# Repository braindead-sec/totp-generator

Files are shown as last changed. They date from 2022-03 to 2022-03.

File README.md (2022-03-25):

# DIY TOTP Generator

A do-it-yourself time-based one-time password generator. You know, for MFA.

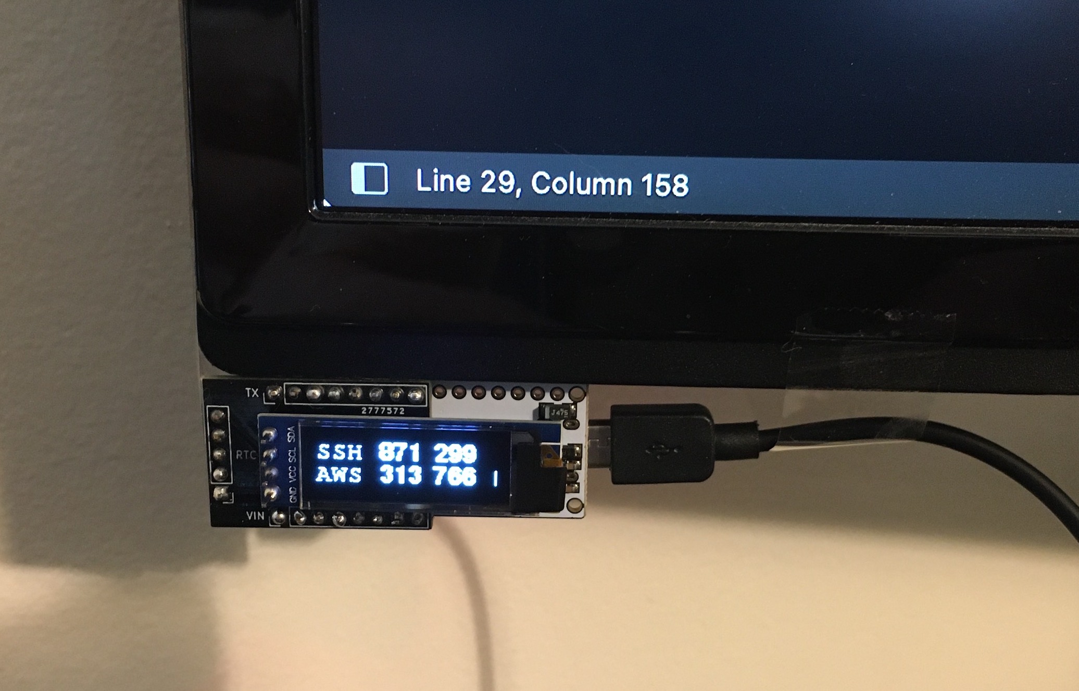
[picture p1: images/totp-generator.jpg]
totp-generator


It's like a cheap open-source [RSA dongle](https://www.tokenguard.com/SecurID-700.asp) that works with any multi-factor authentication service following the [TOTP standard](https://datatracker.ietf.org/doc/html/rfc6238).

Why? Because there are some things I use so frequently (SSH) that it's actually inconvenient to unlock my phone to get the MFA code. With this device mounted on my monitor, I can save *seconds* at a time.

Follow the instructions below to build your own!

### Hardware Components

- Arduino Nano (16MHz ATmega328, 5v) or cheap knock-off
- I2C 128x32 OLED display (SSD1306)
- I2C real-time clock module (DS3231) with battery
- [Custom PCB](custom-pcb/) to integrate components

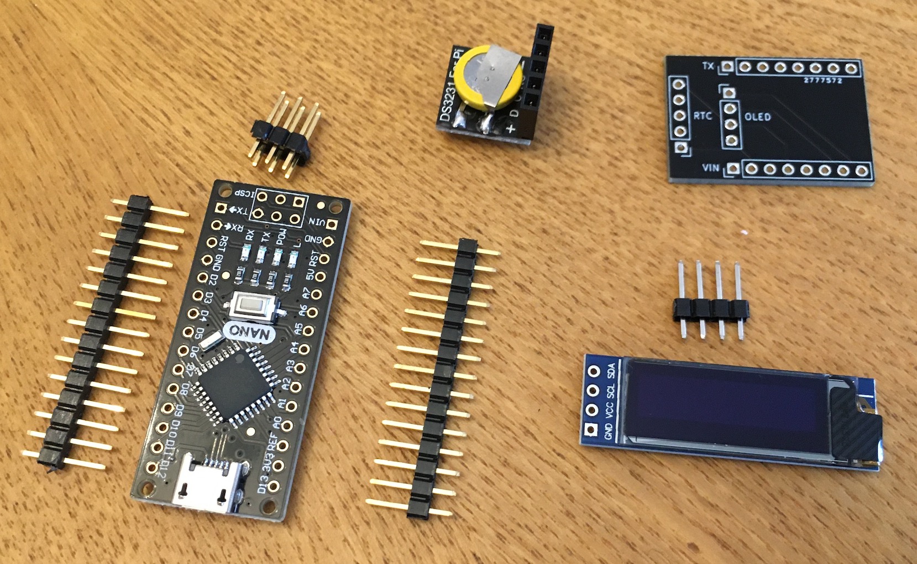
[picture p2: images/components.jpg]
components


### Hardware Assembly

Soldering required. Fine-point solder tip definitely recommended.

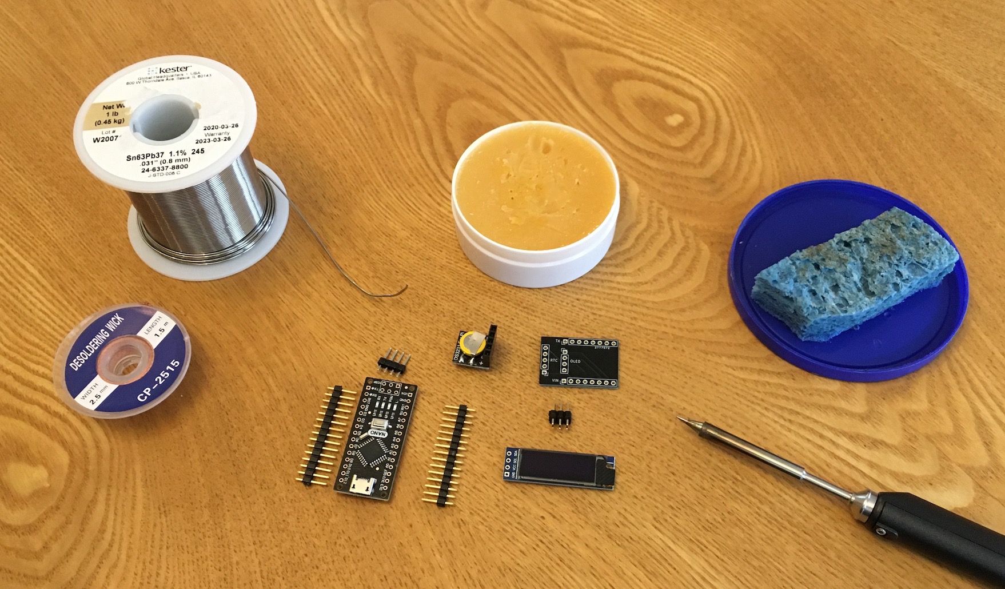
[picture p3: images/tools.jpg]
tools


1. Attach header pins to OLED (short pins and spacers below, long pins above):

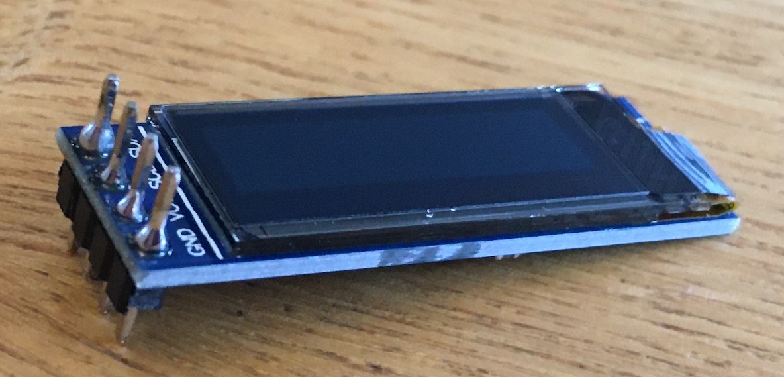
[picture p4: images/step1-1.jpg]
step1-1
   

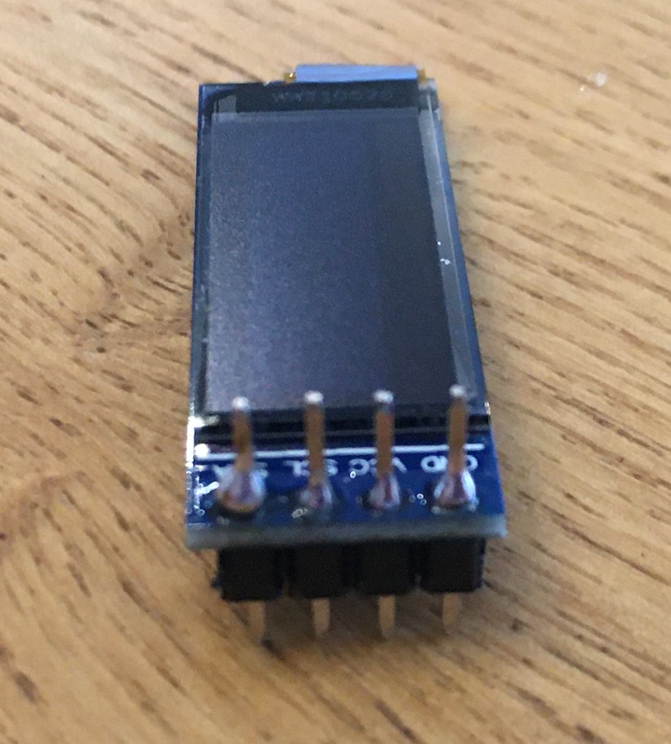
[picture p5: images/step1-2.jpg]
step1-2
   

2. Attach header pins to Nano (note that not all pins are needed). Set the custom PCB in place to make sure the spacing is right - my original design was a hair too wide and set the pins at an angle - but don't solder it in yet. Short pins and spacers should be on the back of the Nano; long pings should protrude through the front:

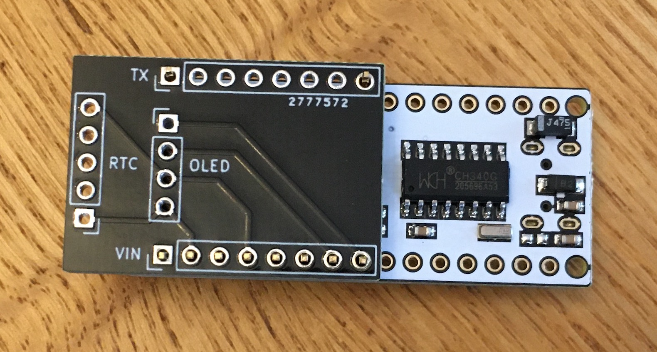
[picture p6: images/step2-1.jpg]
step2-1
   

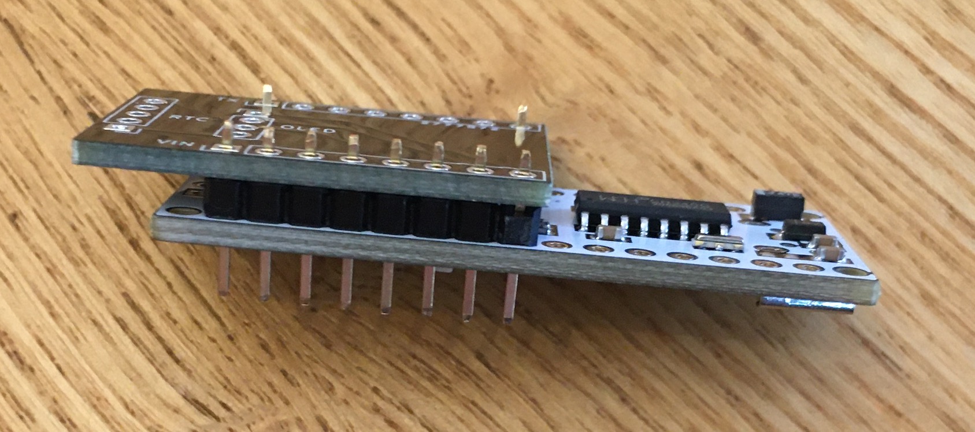
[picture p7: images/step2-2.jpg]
step2-2
   

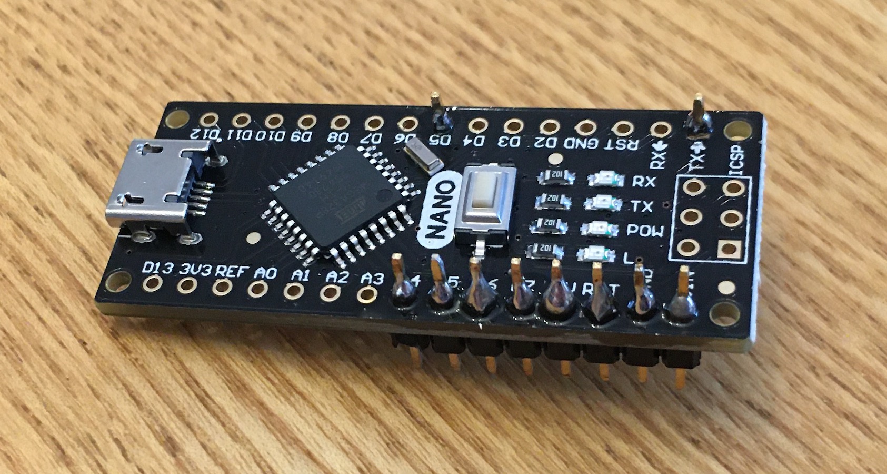
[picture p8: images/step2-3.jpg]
step2-3
   

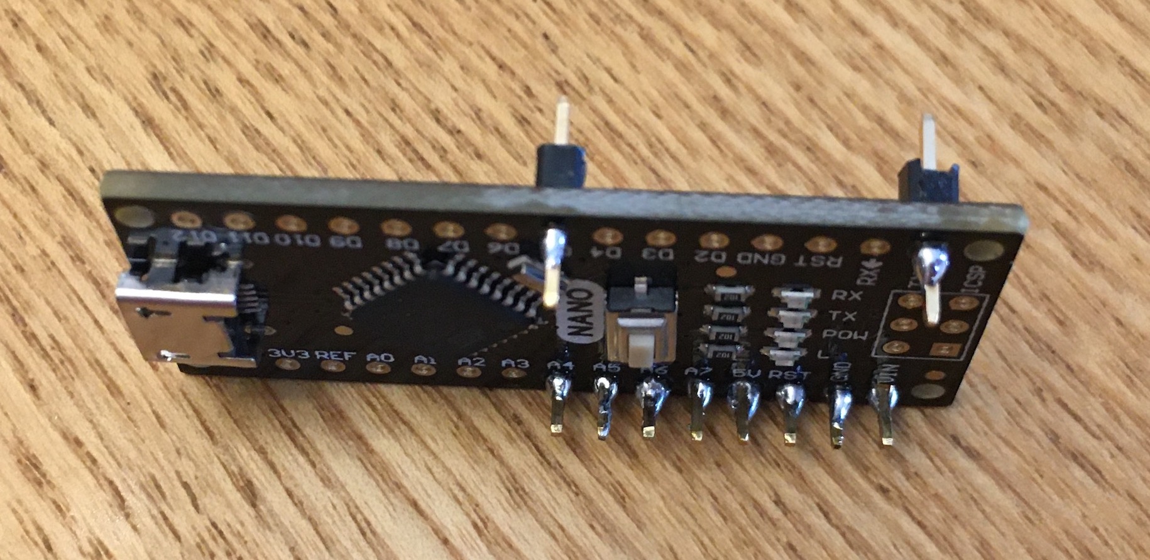
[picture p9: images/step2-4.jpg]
step2-4
   
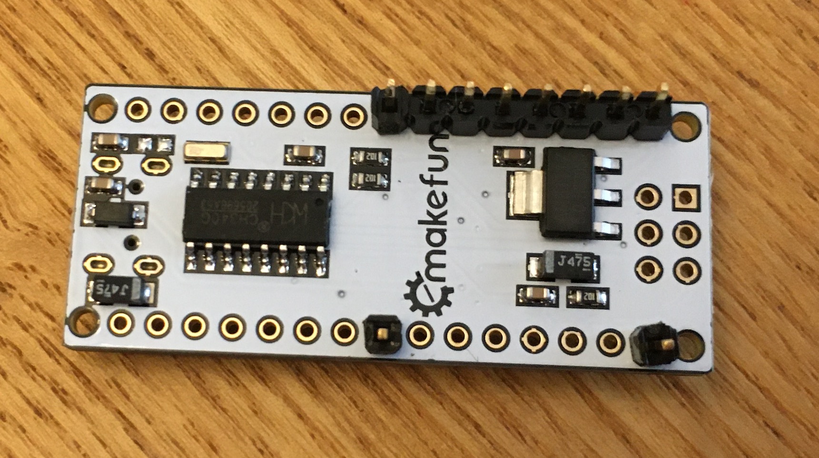
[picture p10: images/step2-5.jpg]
step4-5
   

3. Attach OLED to custom PCB (insert pins through the holes marked OLED, and don't cover the RTC holes!):

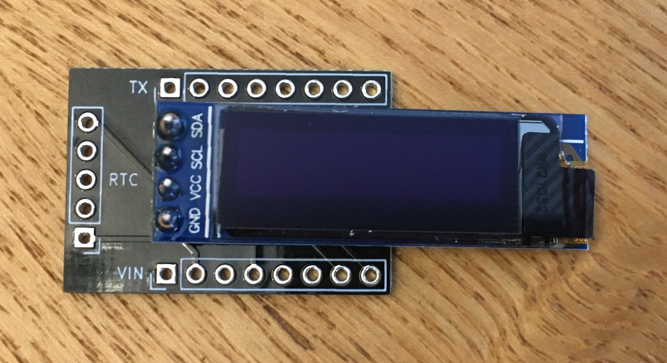
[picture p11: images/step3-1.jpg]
step3-1
   

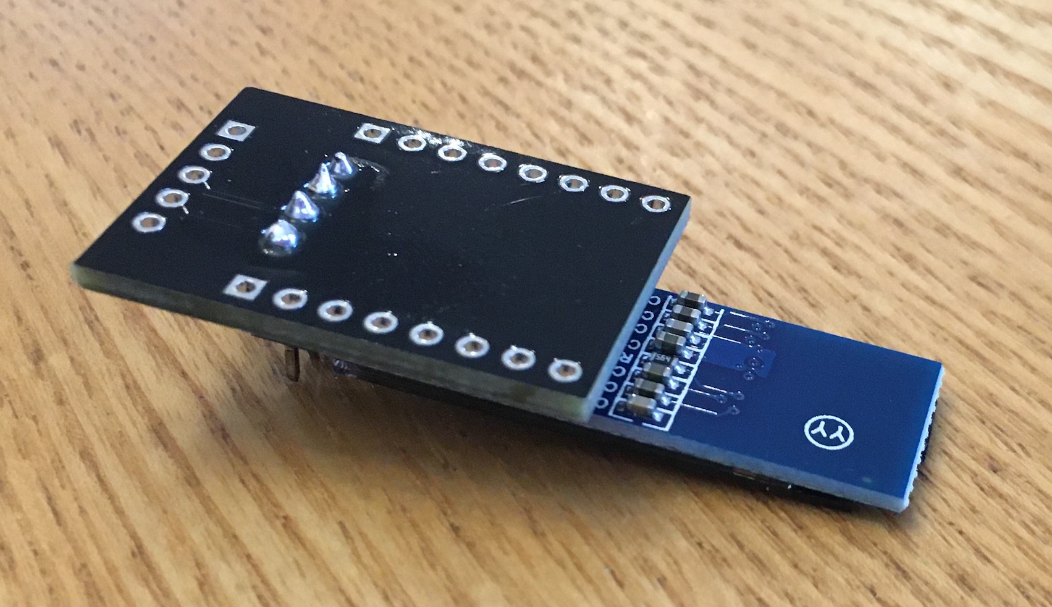
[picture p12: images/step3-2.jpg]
step3-2
   

4. Attach custom PCB to Nano (make sure VIN and TX align on the Nano and custom PCB):

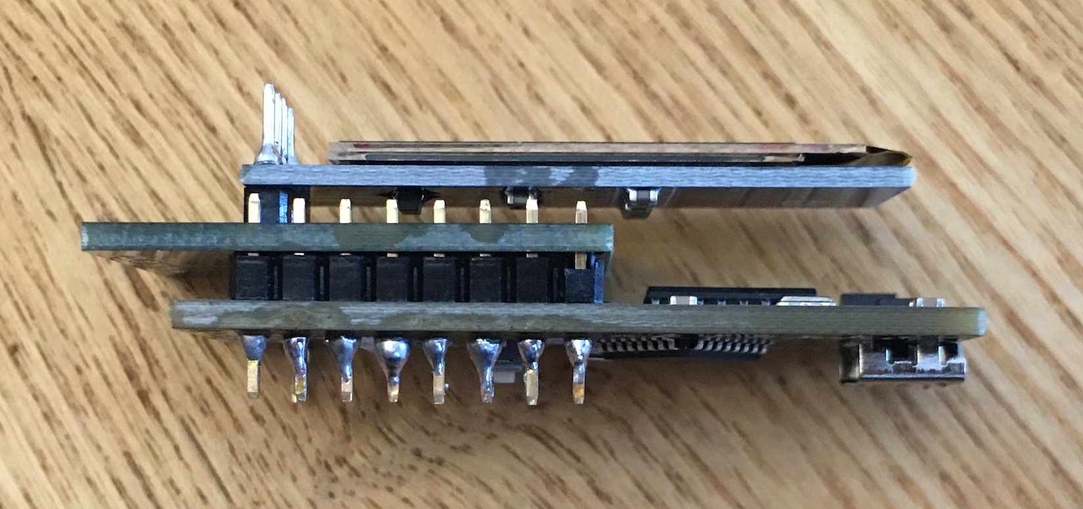
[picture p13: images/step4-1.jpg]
step4-1
   

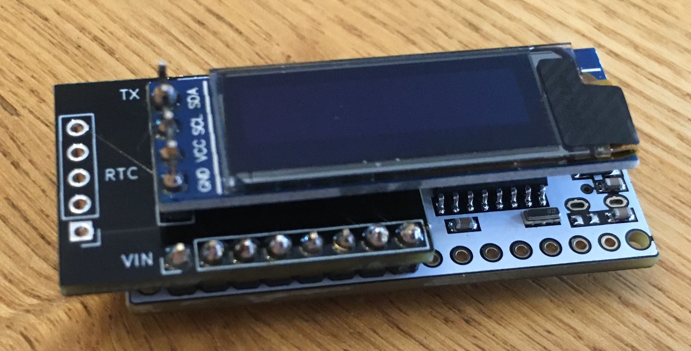
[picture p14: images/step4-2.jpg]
step4-2
   

5. Attach RTC header pins to custom PCB (long pins and spacers below, short pins above):

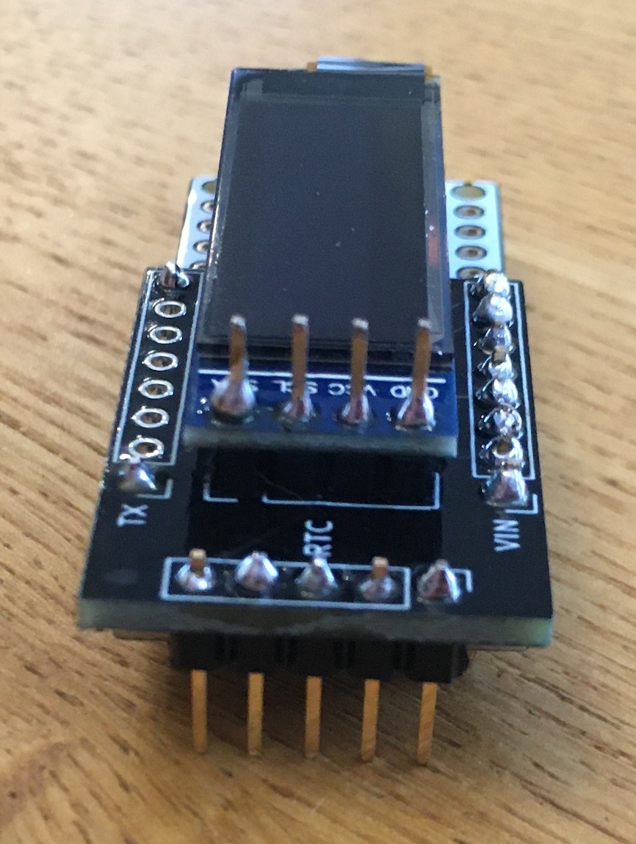
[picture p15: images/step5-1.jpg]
step5-1
   

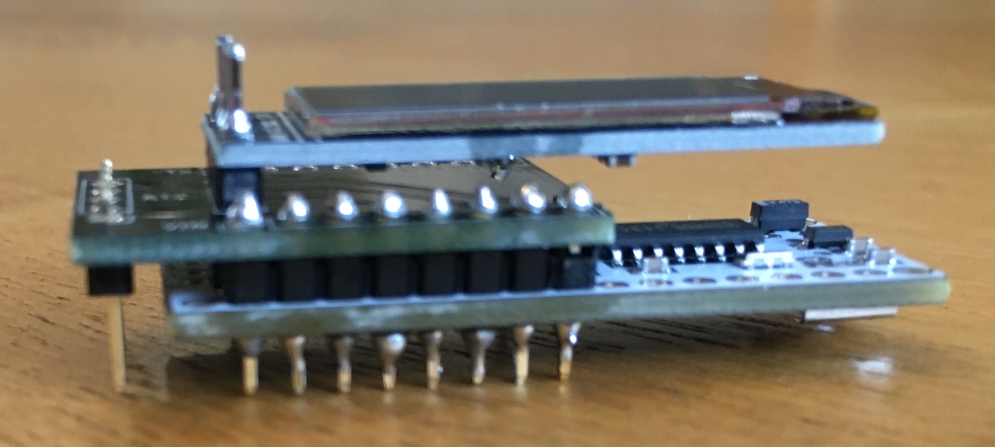
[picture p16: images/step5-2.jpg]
step5-2
   

6. Slide RTC onto its header pins:

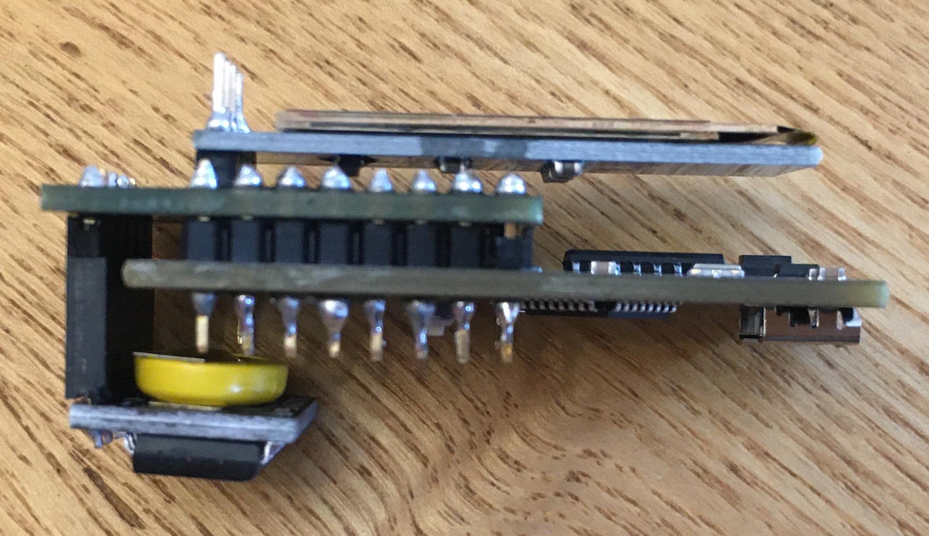
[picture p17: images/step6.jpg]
step6
   

Assembly is now complete!

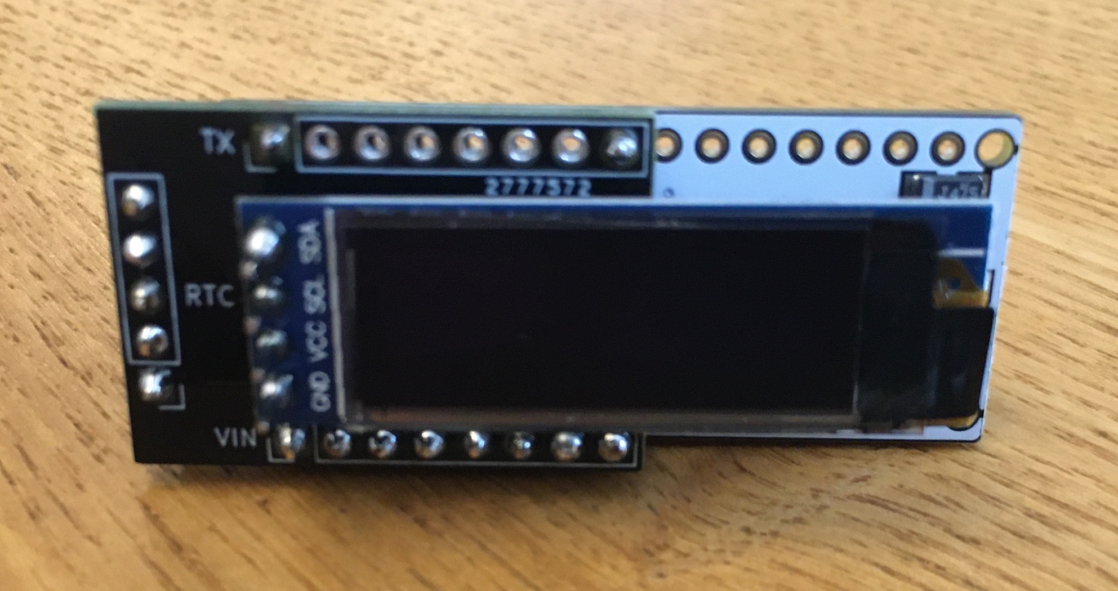
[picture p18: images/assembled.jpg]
assembled


### Software Installation

1. Download [Arduino IDE](https://www.arduino.cc/en/software).

2. [Install required boards](https://support.arduino.cc/hc/en-us/articles/360016119519-How-to-add-boards-in-the-board-manager):

   - `Adafruit AVR Boards` by Adafruit

3. [Install required libraries](https://docs.arduino.cc/software/ide-v1/tutorials/installing-libraries):
   - `Adafruit SSD1306` by Adafruit
   - `Adafruit GFX Library` by Adafruit
   - `RTC` by Manjunath CV
   - `TOTP library` by Luca Dentella

4. Clone or export this GitHub repo.

5. Open the Arduino project (`totp-generator.ino`) in Arduino IDE.

6. Connect your fully assembled device to your computer using a USB data cable. The power light should come on, and it may blink if there is a default program installed to make it do that.

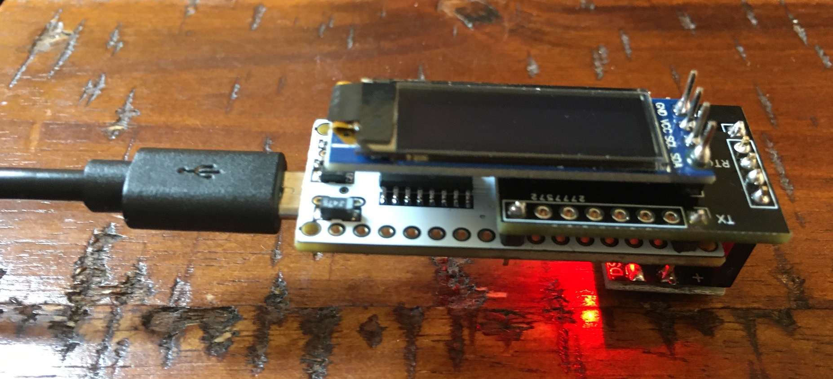
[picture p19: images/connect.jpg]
connect
   

7. From the `Tools` menu in the Arduino IDE, configure these options:
   - Board: Arduino Nano
   - Processor: ATmega 328P
   - Port: whichever one corresponds to the device you just plugged in

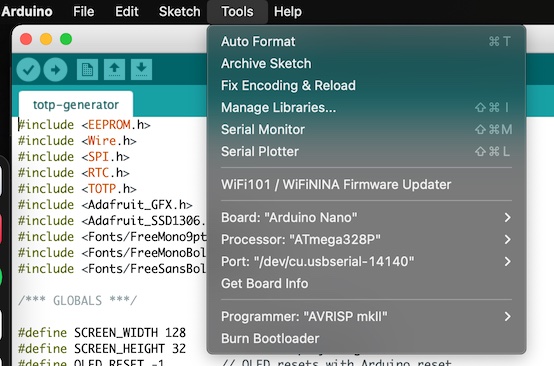
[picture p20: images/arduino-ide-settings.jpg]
arduino-ide-settings
   

8. Click the right-arrow button at the top of the program window to compile the code and upload it to the device.

If everything worked properly up to this point, your device should now be showing either "Connect to set clock" or "Connect to set keys" (depending on the initial RTC setting):

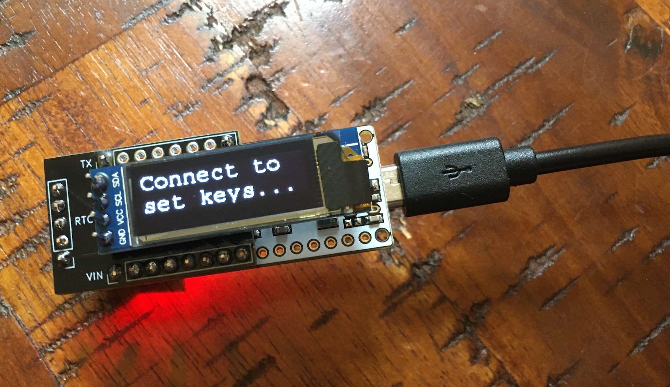
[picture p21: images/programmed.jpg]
programmed


### Software Configuration

1. Install [Python 3](https://www.python.org/downloads/).

2. Install required Python libraries (just `pyserial`):
   
* `pip3 install -r requirements.txt`
   
3. Connect your fully assembled and programmed device to your computer using a USB data cable.

4. Run the Python script:
   
* `python3 setup-device.py`
   
5. Select the USB port corresponding to your device, when prompted.

6. After establishing a serial connection to your device, the script will automatically sync the time from your computer to the RTC.

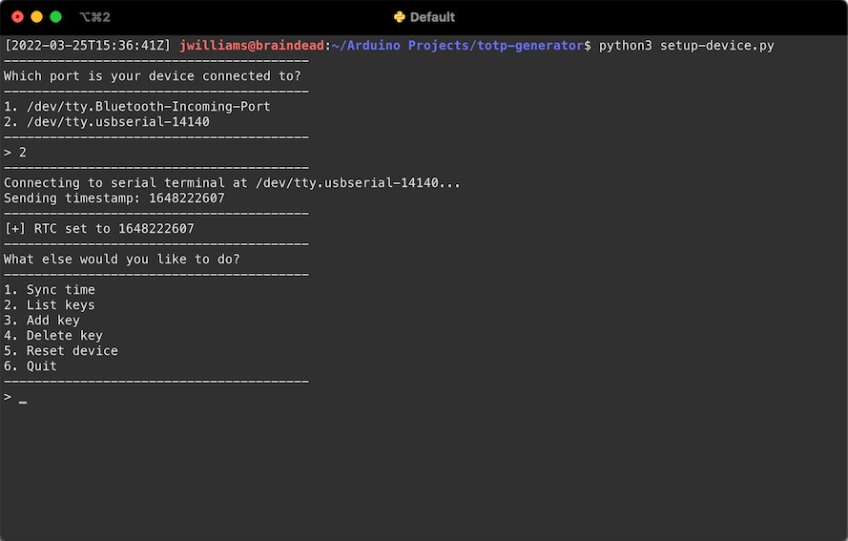
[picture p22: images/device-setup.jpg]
device-setup
   

7. For first-time setup, choose option 5 to initialize the device memory.

8. Choose option 3 to add a key to your device. First enter a three-character label for the key, then enter the key in the standard Base32 format. The device currently supports one or two keys at a time, and will adjust the display accordingly. Keys are recorded in the Arduino's built-in EEPROM without encryption (fair warning).
   - [Google Authenticator](https://support.google.com/accounts/answer/1066447): the app should print your key after completing setup, otherwise you can retrieve the code from the first line of your `.google_authenticator` file
   - [AWS MFA](https://docs.aws.amazon.com/IAM/latest/UserGuide/id_credentials_mfa_enable_virtual.html): use the "Show Secret Key" option during setup

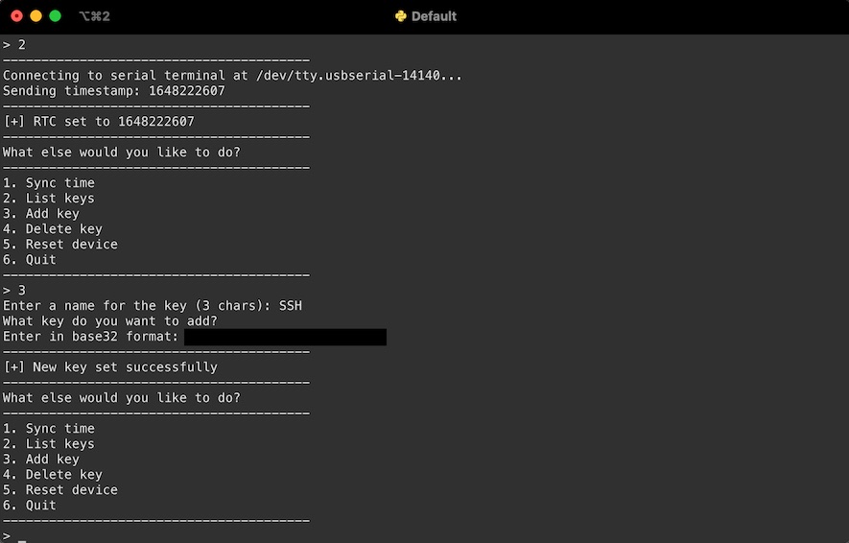
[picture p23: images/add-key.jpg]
add-key
   

9. Use the other menu options to view the labels assigned to keys stored on the device, delete keys, reset the device memory (wipe all keys), and sync the time again. Choose option 6 when you're done.

Setup is now complete! Here's how it should look:

- One key

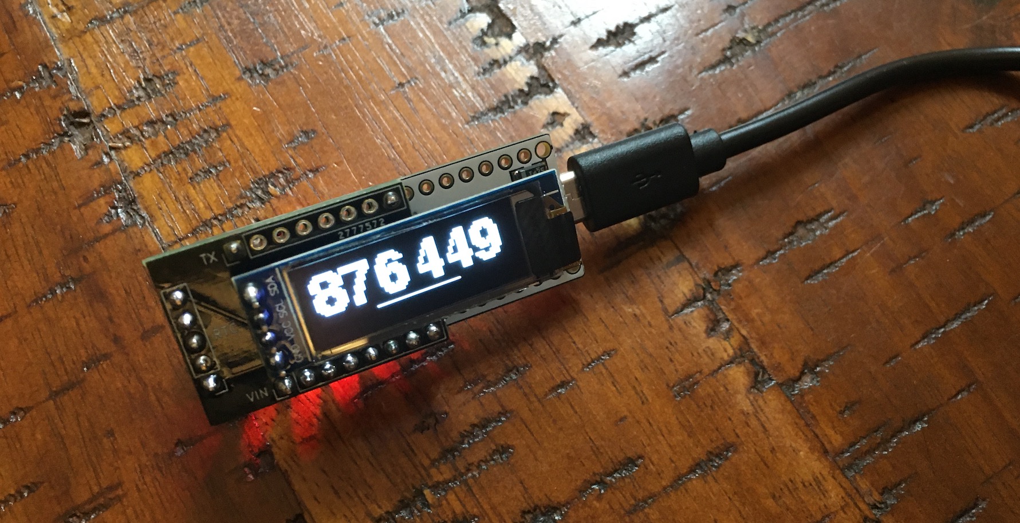
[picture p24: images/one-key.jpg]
one-key
  

- Two keys

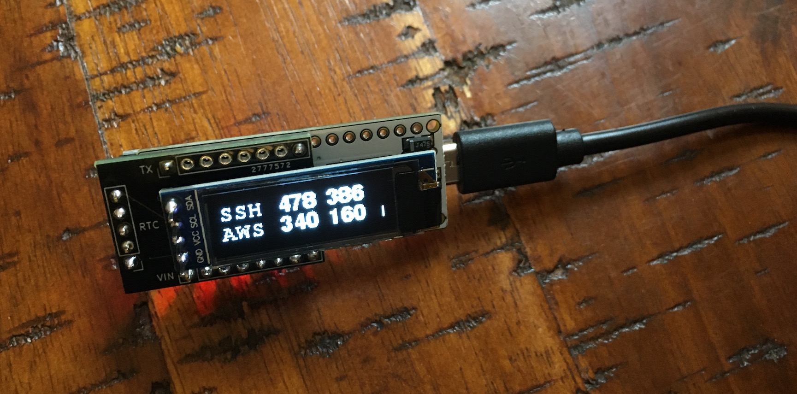
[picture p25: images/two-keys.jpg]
two-keys
  

The display includes a countdown bar to let you know when the code is about to change. It uses a 30-second counter, which is the only time value I've seen used in practice. You can change this value, if necessary, by editing the Arduino code and reprogramming the device.

### Just for Fun ###

if you only intend to use one code, you can modify the Arduino program to use a nicer-looking large font (it's not included by default because of memory constraints).

- Delete this line: `#include <Fonts/FreeMonoBold9pt7b.h>`
- Search for `FreeSansBold9pt7b` and replace all matches with `FreeSansBold18pt7b`
- Delete `display.setTextSize(2);` from the `printCode` function
- Delete all of the code inside the `printTwoCodes` function, so that it just looks like one line: `void printTwoCodes(uint8_t key1, uint8_t key2) {}`
- Compile and upload the new program to your device!

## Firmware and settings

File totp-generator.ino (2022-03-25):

#include <EEPROM.h>
#include <Wire.h>
#include <SPI.h>
#include <RTC.h>
#include <TOTP.h>
#include <Adafruit_GFX.h>
#include <Adafruit_SSD1306.h>
#include <Fonts/FreeMono9pt7b.h>
#include <Fonts/FreeMonoBold9pt7b.h>
#include <Fonts/FreeSansBold9pt7b.h>

/*** GLOBALS ***/

#define SCREEN_WIDTH 128     // OLED display width
#define SCREEN_HEIGHT 32     // OLED display height
#define OLED_RESET -1        // OLED resets with Arduino reset
#define SCREEN_ADDRESS 0x3C  // OLED 2wire bus address

const uint8_t maxKeys = 2;     // Max number of keys to hold
const uint16_t maxKeyLen = 64; // Max key length, in bytes

Adafruit_SSD1306 display(SCREEN_WIDTH, SCREEN_HEIGHT, &Wire, OLED_RESET);
static DS3231 rtc;
uint8_t keysSet = 0;
boolean timeSet = false;

struct DataObj {
  uint16_t keyLen[maxKeys];
  uint8_t keyName[maxKeys][3];
  uint8_t key[maxKeys][maxKeyLen];
};
DataObj settings;

/*** FUNCTIONS ***/

String getTime() {
  String hr = String(rtc.getHours());
  String mn = String(rtc.getMinutes());
  String sc = String(rtc.getSeconds());
  if (hr.length() == 1) hr = "0"+hr;
  if (mn.length() == 1) mn = "0"+mn;
  if (sc.length() == 1) sc = "0"+sc;
  String now = "UTC"+hr+":"+mn+":"+sc;
  return now;
}

void setTime(uint32_t timestamp) {
  rtc.stopClock();
  rtc.setEpoch(timestamp);
  rtc.startClock();
  timeSet = true;
  Serial.print("RTC set to ");
  Serial.println(timestamp);
  printSmallOLED("Time synced!");
  delay(2000);
}

uint8_t getExpiration() {
  uint8_t secs = rtc.getSeconds();
  if (secs >= 30)
    secs = secs - 30;
  return (30 - secs);
}

void printCode(uint8_t keyId) {
  display.clearDisplay();
  display.setFont(&FreeSansBold9pt7b);
  display.setTextSize(2);
  
  TOTP totp = TOTP(settings.key[keyId], settings.keyLen[keyId]);
  char* code = totp.getCode(rtc.getEpoch());
  
  // Print first 3 digits
  display.setCursor(0,24);
  for (uint8_t i=0; i<3; i++)
    display.print(code[i]);
  
  // Print last 3 digits
  display.setCursor(64,24);
  for (uint8_t i=3; i<6; i++)
    display.print(code[i]);
  
  // Print countdown bar
  uint8_t expiry = getExpiration();
  uint8_t progress_length = (SCREEN_WIDTH / 30) * expiry;
  uint8_t progress_start = (SCREEN_WIDTH / 2) - (progress_length / 2);
  display.drawFastHLine(progress_start, SCREEN_HEIGHT - 1, progress_length, SSD1306_WHITE);
  display.display(); 
}

void printTwoCodes(uint8_t key1, uint8_t key2) {
  uint8_t i;
  display.clearDisplay();

  TOTP totp1 = TOTP(settings.key[key1], settings.keyLen[key1]);
  TOTP totp2 = TOTP(settings.key[key2], settings.keyLen[key2]);

  uint32_t timeNow = rtc.getEpoch();
  char* code1 = totp1.getCode(timeNow);
  char* code2 = totp2.getCode(timeNow);
  
  // Print code 1
  display.setTextSize(1);
  display.setFont(&FreeMono9pt7b);
  display.setCursor(0,14);
  for (i=0; i<3; i++)
    display.print((char)settings.keyName[key1][i]);
  display.setFont(&FreeSansBold9pt7b);
  display.setCursor(45,14);
  for (i=0; i<3; i++)
    display.print(code1[i]);
  display.setCursor(83,14);
  for (i=3; i<6; i++)
    display.print(code1[i]);

  // Print code 2
  display.setFont(&FreeMono9pt7b);
  display.setCursor(0,31);
  for (i=0; i<3; i++)
    display.print((char)settings.keyName[key2][i]);
  display.setFont(&FreeSansBold9pt7b);
  display.setCursor(45,31);
  for (i=0; i<3; i++)
    display.print(code2[i]);
  display.setCursor(83,31);
  for (i=3; i<6; i++)
    display.print(code2[i]);

  // Print countdown bar
  uint8_t expiry = getExpiration();
  uint8_t progress_length = (SCREEN_HEIGHT / 30) * expiry;
  display.drawFastVLine(SCREEN_WIDTH - 1, SCREEN_HEIGHT - progress_length, progress_length, SSD1306_WHITE);
  display.display();
}

void printSmallOLED(String text) {
  display.clearDisplay();
  display.setFont(&FreeMono9pt7b);
  display.setTextSize(1);
  display.setCursor(0,11);
  display.print(text);
  display.display();
}

uint8_t getKeyCount() {
  uint8_t numKeys = 0;
  for (uint8_t i=0; i<maxKeys; i++)
    if (settings.keyLen[i] > 0 && settings.keyLen[i] <= maxKeyLen)
      numKeys++;
  return numKeys;
}

void getCommand() {
  String code = Serial.readStringUntil('\n');
  
  if (code == "sync") {
    // Sync the time
    uint32_t newTime = Serial.readStringUntil('\n').toInt();
    setTime(newTime);
  
  } else if (code == "get") {
    // List key names (but not keys)
    // Print the number of keys available
    uint16_t numKeys = getKeyCount();
    Serial.println(numKeys, DEC);
    // Print the ID and name of each
    if (numKeys > 0) {
      for (uint16_t i=0; i<numKeys; i++) {
        Serial.print(i+1);
        Serial.print(": ");
        for (uint8_t j : settings.keyName[i])
          Serial.print(char(j));
        Serial.println();
      }
    }
  
  } else if (code == "set") {
    // Add a new HMAC key
    // Read key name from serial (3 chars)
    String newKeyName = Serial.readStringUntil('\n');
    // Read key from serial
    uint8_t newKey[maxKeyLen];
    uint16_t newKeyLen = Serial.readBytesUntil('\n', newKey, maxKeyLen+1);
    // Make sure there is a key slot available
    uint16_t numKeys = getKeyCount();
    if (numKeys >= maxKeys) {
      Serial.print("Only ");
      Serial.print(maxKeys, DEC);
      Serial.println(" keys allowed");
      return;
    }
    if (newKeyLen >= 10 && newKeyLen <= maxKeyLen) {
      // Update settings
      uint16_t i;
      for (i=0; i<3; i++)
        settings.keyName[numKeys][i] = newKeyName[i];
      settings.keyLen[numKeys] = newKeyLen;
      for (i=0; i<newKeyLen; i++)
        settings.key[numKeys][i] = newKey[i];
      while (i < maxKeyLen) {
        settings.key[numKeys][i] = 0xFF;
        i++;
      }
      EEPROM.put(0, settings);
      // Show result
      keysSet++;
      Serial.println("New key set successfully");
      printSmallOLED("New key set");
      delay(1500);
    } else {
      Serial.println("Invalid key length");
    }

  } else if (code == "del") {
    // Delete an HMAC key
    uint16_t numKeys = getKeyCount();
    // Get the key ID to delete
    uint16_t keyId = Serial.readStringUntil('\n').toInt();
    if (keyId >= numKeys) {
      Serial.println("Invalid key ID");
      return;
    }
    // Cascade remaining keys
    while ((keyId+1) < numKeys) {
      uint16_t i;
      settings.keyLen[keyId] = settings.keyLen[keyId+1];
      for (i=0; i<3; i++)
        settings.keyName[keyId][i] = settings.keyName[keyId+1][i];
      for (i=0; i<maxKeyLen; i++)
        settings.key[keyId][i] = settings.key[keyId+1][i];
      keyId++;
    }
    // Zero out the last available key
    settings.keyLen[keyId] = 0;
    for (uint8_t i : settings.keyName[keyId])
      i = 0xFF;
    for (uint8_t i : settings.key[keyId])
      i = 0xFF;
    // Update settings
    EEPROM.put(0, settings);
    // Show result
    keysSet--;
    Serial.println("Erased key");
    printSmallOLED("Key deleted");
    delay(1500);
 
  } else if (code == "wipe") {
    // Reset all settings to defaults
    for (uint16_t i=0; i<maxKeys; i++) {
      settings.keyLen[i] = 0;
      for (uint8_t j : settings.keyName[i]) 
        j = 0xFF;
      for (uint8_t j : settings.key[i]) 
        j = 0xFF;
    }
    EEPROM.put(0, settings);
    keysSet = 0;
    // Reset clock
    rtc.stopClock();
    rtc.setEpoch(0);
    timeSet = false;
    Serial.println("Settings reset");
    printSmallOLED("Settings\nreset");
    delay(2500);
    
  } else {
    // Error for unrecognized command
    Serial.println("Bad command received");
    printSmallOLED("Bad command\nreceived");
    delay(1500);
  }
}

/*** MAIN ***/

void setup() {
  
  // Init serial
  Serial.begin(115200);
  
  // Init OLED display
  if (!display.begin(SSD1306_SWITCHCAPVCC, SCREEN_ADDRESS)) {
    Serial.println("OLED init failed");
    while(1);
  }
  display.setTextColor(SSD1306_WHITE);
  
  // Init real-time clock
  rtc.begin();
  rtc.setHourMode(CLOCK_H24);
  if (rtc.getEpoch() > 1640995200) // 1/1/2022
    timeSet = true;

  // Load settings from EEPROM
  EEPROM.get(0, settings);
  keysSet = getKeyCount();
  
}

void loop() {
  
  // Check for serial command
  if (Serial.available())
    getCommand();

  // Show MFA token (or error message)
  if (timeSet == false) {
    printSmallOLED("Connect to\nset clock...");
  } else if (keysSet == 2) {
      printTwoCodes(0, 1);
  } else if (keysSet == 1) {
      printCode(0);
  } else {
    printSmallOLED("Connect to\nset keys...");
  }
  
  // Repeat 5x/second
  // Faster RTC polling causes unexpected results
  delay(200);

}

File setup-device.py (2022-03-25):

#!/usr/bin/env python3

import sys
import math
import datetime
import time
import glob
import base64

import serial

### FUNCTIONS ###

def print_bar():
    print('-' * 40)

# Find available serial ports
def get_serial_ports():
    if sys.platform.startswith('win'):
        ports = ['COM%s' % (i + 1) for i in range(256)]
    elif sys.platform.startswith('linux') or sys.platform.startswith('cygwin'):
        # this excludes your current terminal "/dev/tty"
        ports = glob.glob('/dev/tty[A-Za-z]*')
    elif sys.platform.startswith('darwin'):
        ports = glob.glob('/dev/tty.*')
    else:
        print('Unsupported platform.')
        sys.exit(1)
    result = []
    for port in ports:
        try:
            s = serial.Serial(port)
            s.close()
            result.append(port)
        except (OSError, serial.SerialException):
            pass
    if len(result) == 0:
        print('No serial ports available.')
        sys.exit(1)
    return result

# Intialize serial connection
def serial_connect(usb_tty):
    try:
        return serial.Serial(usb_tty, 115200)
    except:
        time.sleep(2)
        serial_connect(usb_tty)

# Send one message via serial
def serial_send(msg, encode=True):
    if encode:
        tty.write('{}\n'.format(msg).encode('utf-8'))
    else:
        tty.write(msg)
        tty.write('\n'.encode('utf-8'))

# Receive one message via serial
def serial_receive():
    print_bar()
    print('[+] {}'.format(tty.readline().decode('utf-8')), end='')

# Receive one message via serial without printing
def serial_get():
    return tty.readline().decode('utf-8')

# Get current UTC timestamp
def get_now():
    now = datetime.datetime.now()
    ts = math.trunc(datetime.datetime.timestamp(now))
    return ts

# Sync time from computer to the device
def sync_time():
    serial_send('sync')
    now = get_now()
    print('Sending timestamp: {}'.format(now))
    serial_send(now)
    serial_receive()

# Read key from the device
def get_key():
    serial_send('get')
    result = int(serial_get())
    if result == 0:
        print_bar()
        print('[+] No keys set')
    else:
        while result > 0:
            serial_receive()
            result -= 1

# Write keys to the device
def set_key():
    # Get key name
    key_name = input('Enter a name for the key (3 chars): ')[0:3]
    # Pad to 3 chars if necessary
    while len(key_name) < 3:
        key_name += ' ' 
    print('What key do you want to add?')
    try:
        # Get key in base32 format
        b32_key = input('Enter in base32 format: ')
        # Add padding if necessary
        while len(b32_key) % 8 > 0:
            b32_key = b32_key + '='
        # Convert to hexadecimal
        hex_key = base64.b32decode(b32_key)
    except:
        print('[+] Invalid key')
        return
    serial_send('set')
    serial_send(key_name)
    serial_send(hex_key, False)
    serial_receive()

# Delete key from the device
def del_key():
    get_key()
    print_bar()
    key_id = int(input('Which key do you want to delete? ')) - 1
    serial_send('del')
    serial_send(key_id)
    serial_receive()

# Reset device settings
def reset():
    serial_send('wipe')
    serial_receive()

### MAIN ###

# Choose a serial port
menu = get_serial_ports()
print_bar()
print('Which port is your device connected to?')
print_bar()
for i in range(1, len(menu)+1):
    print('{}. {}'.format(i, menu[i-1]))
print_bar()
selection = input('> ')
try:
    usb_tty = menu[int(selection)-1]
except:
    print('Invalid selection. Bye!')
    sys.exit(1)

# Connect to serial terminal and sync time
print_bar()
print('Connecting to serial terminal at {}...'.format(usb_tty))
tty = serial_connect(usb_tty)
time.sleep(2)
sync_time()

# Show menu with other options
menu = [
    'Sync time',
    'List keys',
    'Add key',
    'Delete key',
    'Reset device',
    'Quit'
]
while True:
    print_bar()
    print('What else would you like to do?')
    print_bar()
    for i in range(1, len(menu)+1):
        print('{}. {}'.format(i, menu[i-1]))
    print_bar()
    selection = int(input('> '))
    if selection < len(menu)+1:
        if selection == 1:
            sync_time()
        elif selection == 2:
            get_key()
        elif selection == 3:
            set_key()
        elif selection == 4:
            del_key()
        elif selection == 5:
            reset()
        elif selection == 6:
            break
    else:
        print('Poor choice. Try again.')

# Clean up and quit
print('OK bye!')
tty.close()
